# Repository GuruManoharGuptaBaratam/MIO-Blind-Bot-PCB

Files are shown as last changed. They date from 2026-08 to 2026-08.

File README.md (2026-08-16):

<div align="center">

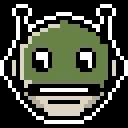
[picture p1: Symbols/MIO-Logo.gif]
MIO Logo


# MIO-Blind-Bot-PCB

**Custom hardware design for MIO — a wearable assistive device for blind and low-vision users**


[]()
[]()
[]()

</div>

---

## About This Repository

This repository contains the complete PCB hardware design for **MIO**, a dual-ESP32 wearable assistive device. The board serves as the central interconnect and power-management platform of the system, tying together the compute modules, motion sensing, camera pan-tilt actuation, display feedback, and battery power delivery into a single wearable-ready design.

This is a hardware-only repository — schematics, PCB layout, manufacturing outputs, and supporting documentation live here. Firmware for the system is maintained separately.

### Key Subsystems

- **Dual ESP32 compute architecture** — separate Core and Inference module footprints
- **ESP32-CAM interconnect** — pan-tilt servo header + camera signal breakout
- **Power management** — single-cell Li-ion BMS input, with onboard 5V (CA-1235) and 3.3V (LM2596) regulation stages
- **IMU integration** — MPU6050 motion/orientation sensor interface
- **Display interface** — 1.8" ST7735 TFT (SPI) connector
- **Servo control headers** — MG90S-compatible pan/tilt outputs

---

## Board Renders

<div align="center">

| Front | Back |
|:---:|:---:|
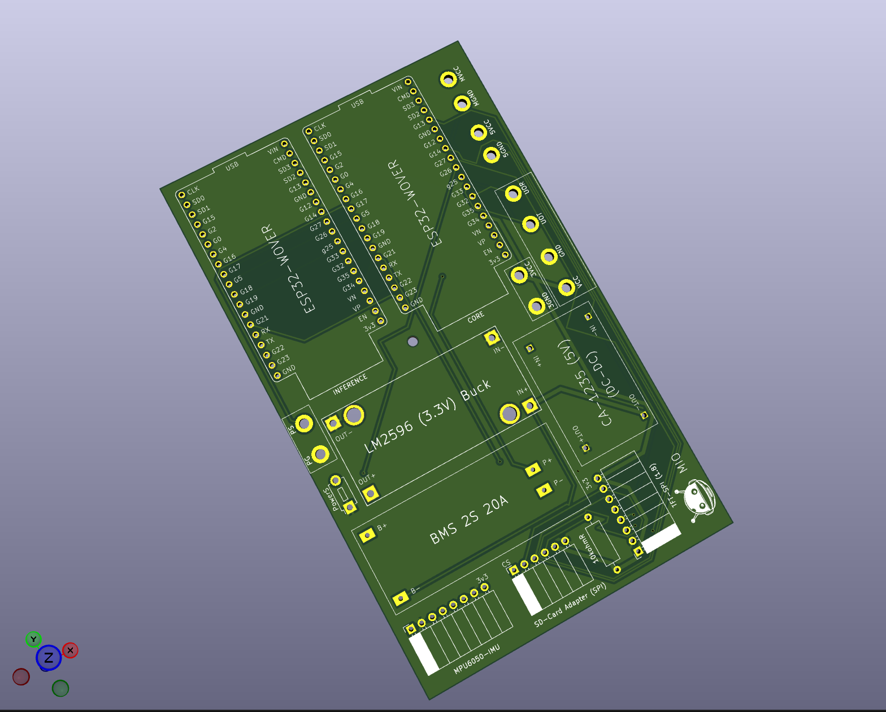
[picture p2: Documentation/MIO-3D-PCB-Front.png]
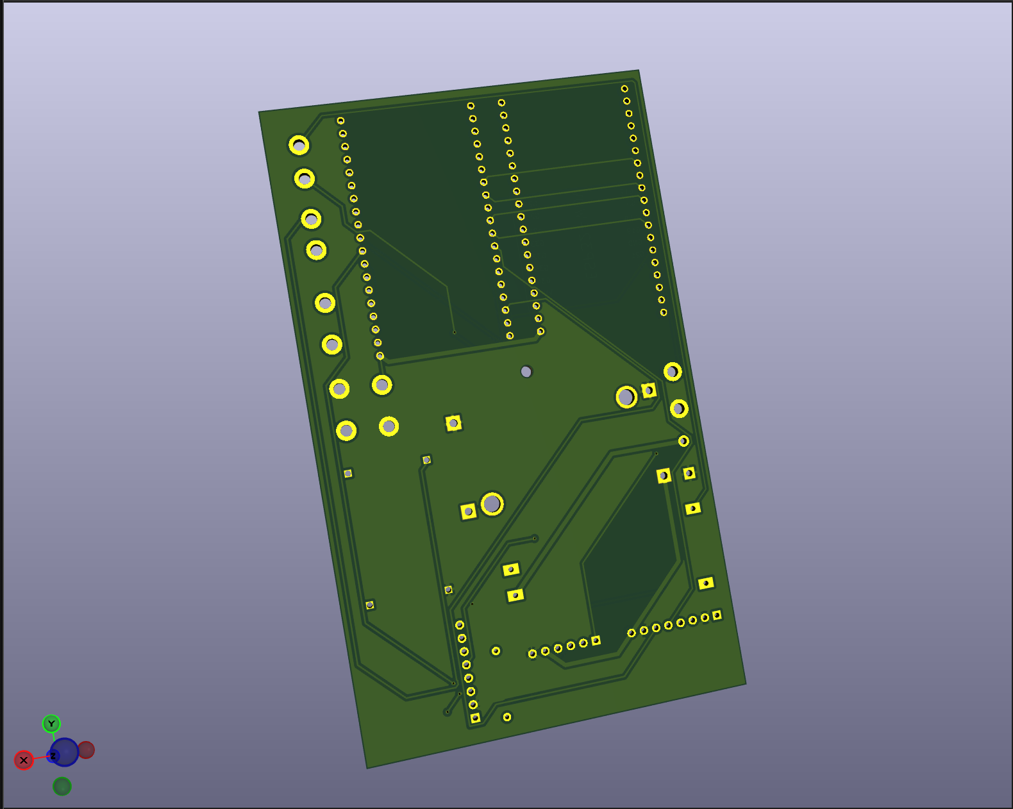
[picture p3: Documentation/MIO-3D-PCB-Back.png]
|  |  |

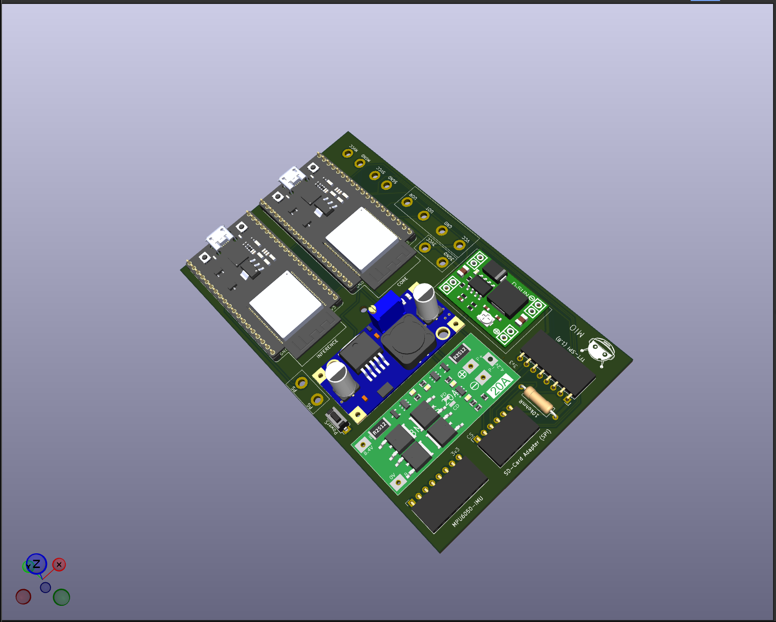
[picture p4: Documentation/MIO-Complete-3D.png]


**[▶ Watch the 3D board walkthrough](Documentation/MIO-3D-Video.mp4)**

</div>

---

## PCB Layout

<div align="center">
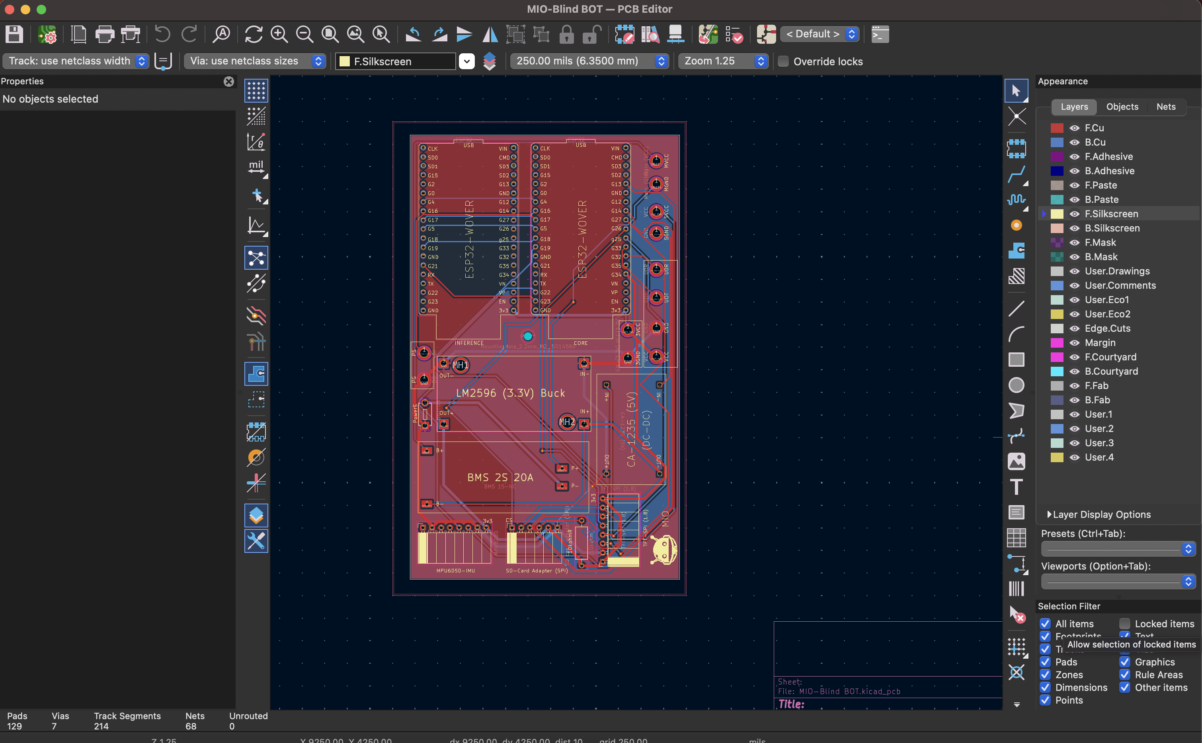
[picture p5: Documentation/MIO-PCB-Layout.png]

</div>

---

## Schematics

The full schematic set is available as PDF for quick review without opening KiCad:

- [MIO Schematic — Sheet 1](Documentation/MIO-Schematic%281%29.pdf)
- [MIO Schematic — Sheet 2](Documentation/MIO-Schematic%282%29.pdf)

For the editable source, see [`Hardware/MIO-Blind BOT.kicad_sch`](Hardware/MIO-Blind%20BOT.kicad_sch).

---

## Footprints & 3D Models

Custom footprints and 3D models used in this design are included so the project can be opened and rendered without missing library references. Each subfolder is a standalone KiCad footprint library (`.pretty`-style) containing the `.kicad_mod` definition and matching `.step` model.

| Folder | Used For |
|---|---|
| [`BMS-2S 20A`](Footprints/BMS-2S%2020A) | Battery management module (U8) |
| [`CA-1235 (Step-Down)`](Footprints/CA-1235%20%28Step-Down%29) | 5V step-down converter (U5) |
| [`ESP32-CAM`](Footprints/ESP32-CAM) | ESP32-CAM module footprint |
| [`ESP32-DEVKITC-32E`](Footprints/ESP32-DEVKITC-32E) | ESP32 DevKit footprint (Core / Inference modules) |
| [`LM2596-Buck(DC-DC)`](Footprints/LM2596-Buck%28DC-DC%29) | 3.3V buck converter (U12) |
| [`MIO-PCB-Logo`](Footprints/MIO-PCB-Logo) | Silkscreen logo footprint |
| [`ON-OFF Switch`](Footprints/ON-OFF%20Switch) | Power on/off switch |

**To use these in KiCad:**

1. Open **Preferences → Manage Footprint Libraries**.
2. Add each folder under [`Footprints/`](Footprints) as its own library entry (or point to the parent folder if your KiCad version supports nested library discovery).
3. Confirm each footprint's **3D Models** tab (Footprint Properties) is correctly linked to its `.step` file — this is what drives the renders in the [Board Renders](#board-renders) section above.

---

## Manufacturing Files

Ready-to-fabricate outputs are provided for direct submission to a PCB manufacturer (JLCPCB, PCBWay, or equivalent), plus a Bill of Materials for sourcing components.

<div align="center">

### [⬇ Download Gerbers (MIO-Gerber.zip)](Manfacturing/MIO-Gerber.zip) &nbsp;|&nbsp; [⬇ Download BOM (MIO-Blind BOT.csv)](Manfacturing/MIO-Blind%20BOT.csv)

</div>

| File / Folder | Description |
|---|---|
| [`MIO-Gerber.zip`](Manfacturing/MIO-Gerber.zip) | Complete Gerber file set for fabrication |
| [`MIO-Gerbers/`](Manfacturing/MIO-Gerbers) | Unpacked Gerber layer files |
| [`MIO-Drill/`](Manfacturing/MIO-Drill) | Drill files (NC drill / Excellon) |
| [`MIO-Blind BOT.csv`](Manfacturing/MIO-Blind%20BOT.csv) | Bill of Materials (BOM) |

---

## Repository Structure

```
MIO-Blind-Bot-PCB/
├── Documentation/
│   ├── MIO-3D-PCB-Back.png
│   ├── MIO-3D-PCB-Front.png
│   ├── MIO-3D-Video.mp4
│   ├── MIO-Complete-3D.png
│   ├── MIO-PCB-Layout.png
│   ├── MIO-Schematic(1).pdf
│   └── MIO-Schematic(2).pdf
├── Hardware/
│   ├── MIO-Blind BOT.kicad_pcb
│   ├── MIO-Blind BOT.kicad_pro
│   └── MIO-Blind BOT.kicad_sch
├── Manfacturing/
│   ├── MIO-Drill/
│   ├── MIO-Gerbers/
│   ├── MIO-Blind BOT.csv
│   └── MIO-Gerber.zip
├── Footprints/
│   ├── BMS-2S 20A/
│   ├── CA-1235 (Step-Down)/
│   ├── ESP32-CAM/
│   ├── ESP32-DEVKITC-32E/
│   ├── LM2596-Buck(DC-DC)/
│   ├── MIO-PCB-Logo/
│   └── ON-OFF Switch/
├── Symbols/
│   └── MIO-Logo.gif
└── README.md
```

---

## Design Environment

| | |
|---|---|
| **EDA Tool** | [KiCad](https://www.kicad.org/) 10.0 |
| **Layers** | 2-layer (F.Cu / B.Cu) |
| **Design Type** | Wearable power & interconnect board |
| **First Revision** | First custom PCB design for the MIO project |

---

## Getting Started

To open and edit this design locally:

1. Install [KiCad](https://www.kicad.org/download/) (v8 or later recommended).
2. Clone this repository:
   ```bash
        git clone https://github.com/GuruManoharGuptaBaratam/MIO-Blind-Bot-PCB.git
   ```
3. Open [`Hardware/MIO-Blind BOT.kicad_pro`](Hardware/MIO-Blind%20BOT.kicad_pro) in KiCad.

To order the board as-is, download [`MIO-Gerber.zip`](Manfacturing/MIO-Gerber.zip) above and upload it directly to your preferred PCB fabricator. Use [`MIO-Blind BOT.csv`](Manfacturing/MIO-Blind%20BOT.csv) to source and place components.

---

## Roadmap

- [x] Footprint library (`.kicad_mod`) and 3D models (`.step`)
- [ ] Bring-up and test notes

---

## License

License to be finalized — see repository for updates.

---

<div align="center">
<sub>Part of the <b>MIO</b> project.</sub>
</div>

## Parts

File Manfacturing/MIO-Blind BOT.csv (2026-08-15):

Reference | Qty | Value | DNP | Exclude from BOM | Exclude from Board | Exclude from Simulation | Exclude from Position Files | Footprint | Datasheet
U12 | 1 | LM2596 (3.3v) |  |  |  |  | ${EXCLUDE_FROM_POS_FILES} | LM2596-Buck(DC-DC):CONV_USA_MC00100
U11 | 1 | BUTTON |  |  |  |  | ${EXCLUDE_FROM_POS_FILES} | Button_Switch_THT:SW_PUSH_1P1T_6x3.5mm_H5.0_APEM_MJTP1250
U9 | 1 | TFT SPI (1.8) |  |  |  |  | ${EXCLUDE_FROM_POS_FILES} | Connector_PinSocket_2.54mm:PinSocket_1x08_P2.54mm_Horizontal
U8 | 1 | BMS 1S-NC |  |  |  |  | ${EXCLUDE_FROM_POS_FILES} | BMS-2S 20A:BMS-2S 20A
U5 | 1 | CA-1235 (5V) |  |  |  |  | ${EXCLUDE_FROM_POS_FILES} | CA-1235 (Step-Down):Converter_MP1495_Module
U4 | 1 | SD card adapter (SPI) |  |  |  |  | ${EXCLUDE_FROM_POS_FILES} | Connector_PinSocket_2.54mm:PinSocket_1x06_P2.54mm_Horizontal
P1 | 1 | MPU6050 |  |  |  |  | ${EXCLUDE_FROM_POS_FILES} | Connector_PinSocket_2.54mm:PinSocket_1x08_P2.54mm_Horizontal
L1 | 1 | (10kohm) |  |  |  |  | ${EXCLUDE_FROM_POS_FILES} | Resistor_THT:R_Axial_DIN0309_L9.0mm_D3.2mm_P12.70mm_Horizontal
CORE1,INFERENCE1 | 2 | ESP32 |  |  |  |  | ${EXCLUDE_FROM_POS_FILES} | ESP32-DEVKITC-32E:MODULE_ESP32-DEVKITC-32E

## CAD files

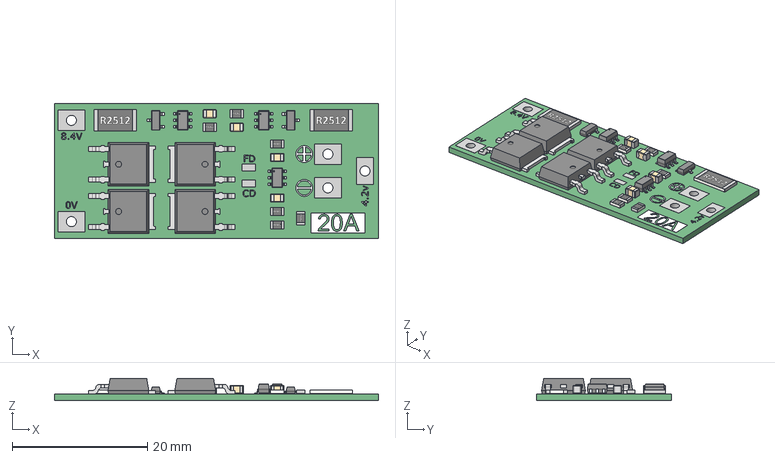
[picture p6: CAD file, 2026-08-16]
Footprints/BMS-2S 20A/HW-391 2S 20A BMS.step
48.0 x 20.0 x 3.31 mm

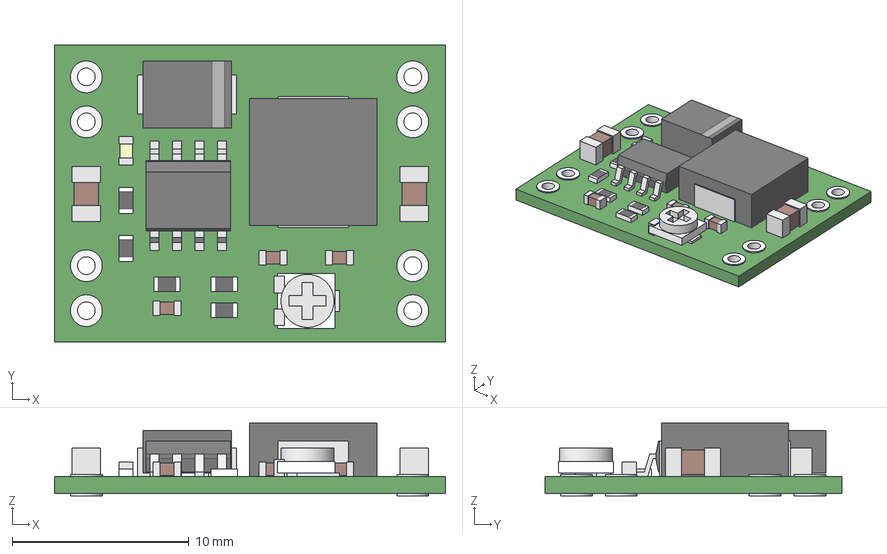
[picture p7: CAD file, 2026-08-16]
Footprints/CA-1235 (Step-Down)/D-SUN_dcdc_step_down_Simple_NoSilk_.step
22.1 x 16.8 x 4.10 mm
main001
pins
comp-top

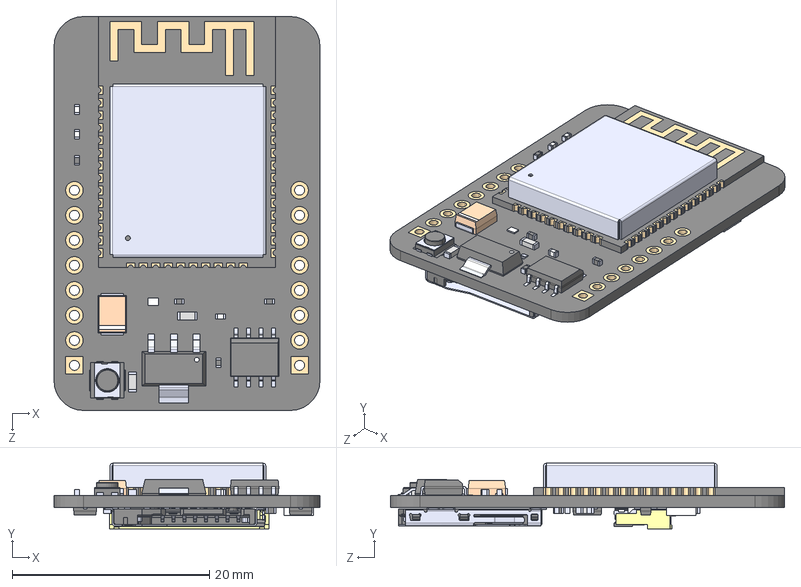
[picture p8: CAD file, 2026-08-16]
Footprints/ESP32-CAM/ESP32-CAM.step
27.0 x 6.65 x 40.0 mm

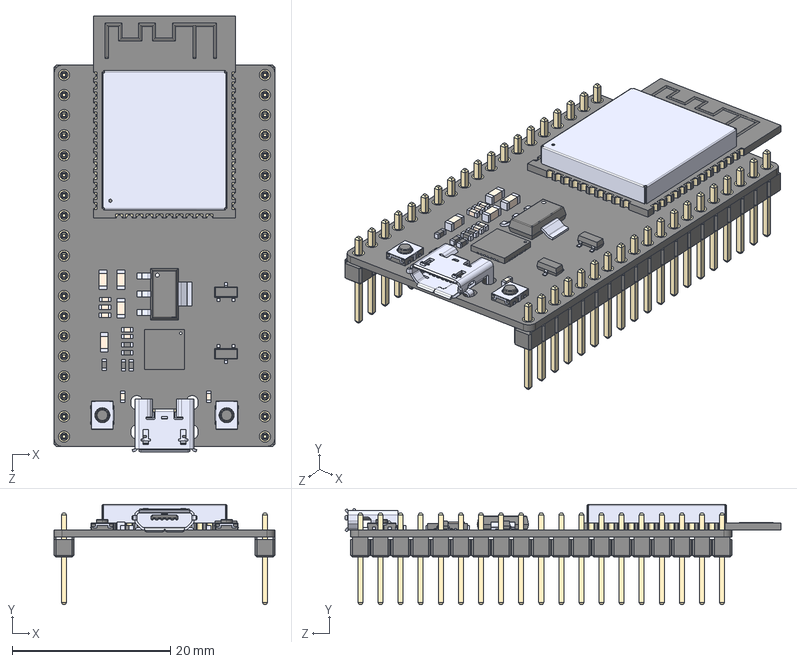
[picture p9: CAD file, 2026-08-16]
Footprints/ESP32-DEVKITC-32E/ESP32-DEVKITC-32E.step
27.9 x 12.7 x 55.1 mm
board
header x 2
ESP32-WROOM-32D
micro usb
button x 2
CP2102N-A01-GQFN28
AMS1117-3.3
SS8050-G
components^DEVKIT V1 ESP32-WROOM-32

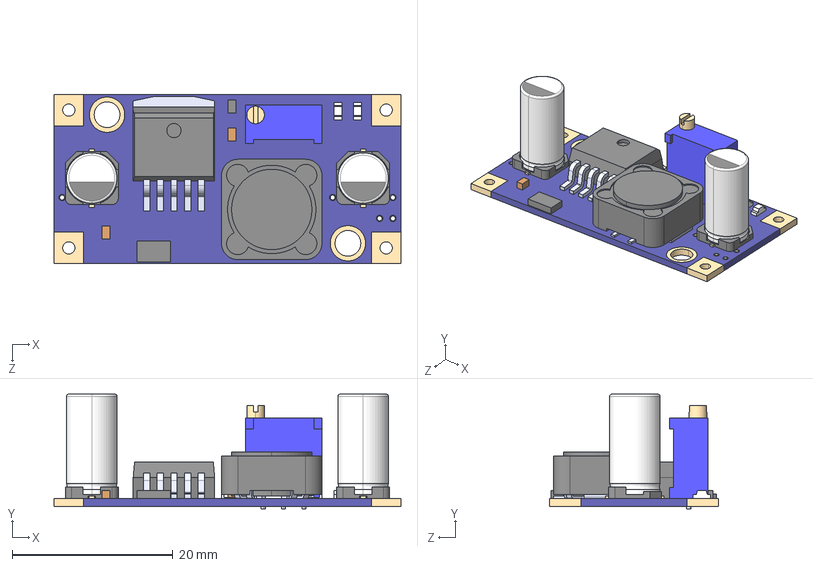
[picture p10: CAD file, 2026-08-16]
Footprints/LM2596-Buck(DC-DC)/007-386628000331258--3DModel-STEP-269445.STEP
43.2 x 14.3 x 21.1 mm
MC00100
3296W-1-104
DR125-331-R
LM2596DSADJG
EEE1HA470XAP x 2

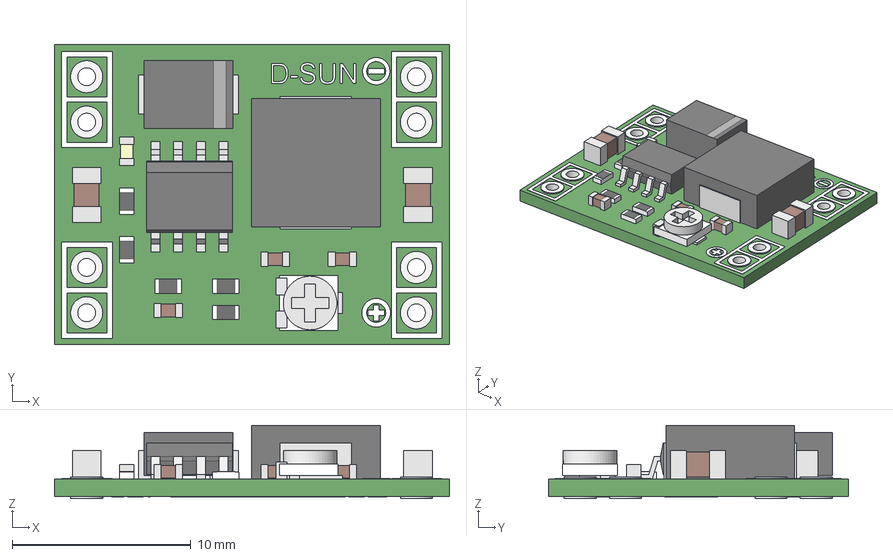
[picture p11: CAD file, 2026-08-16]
Footprints/CA-1235 (Step-Down)/D-SUN_dcdc_step_down_SIMPLE.step
22.1 x 16.8 x 4.10 mm
main001
silk-TOP
pins
silk-bot
comp-top

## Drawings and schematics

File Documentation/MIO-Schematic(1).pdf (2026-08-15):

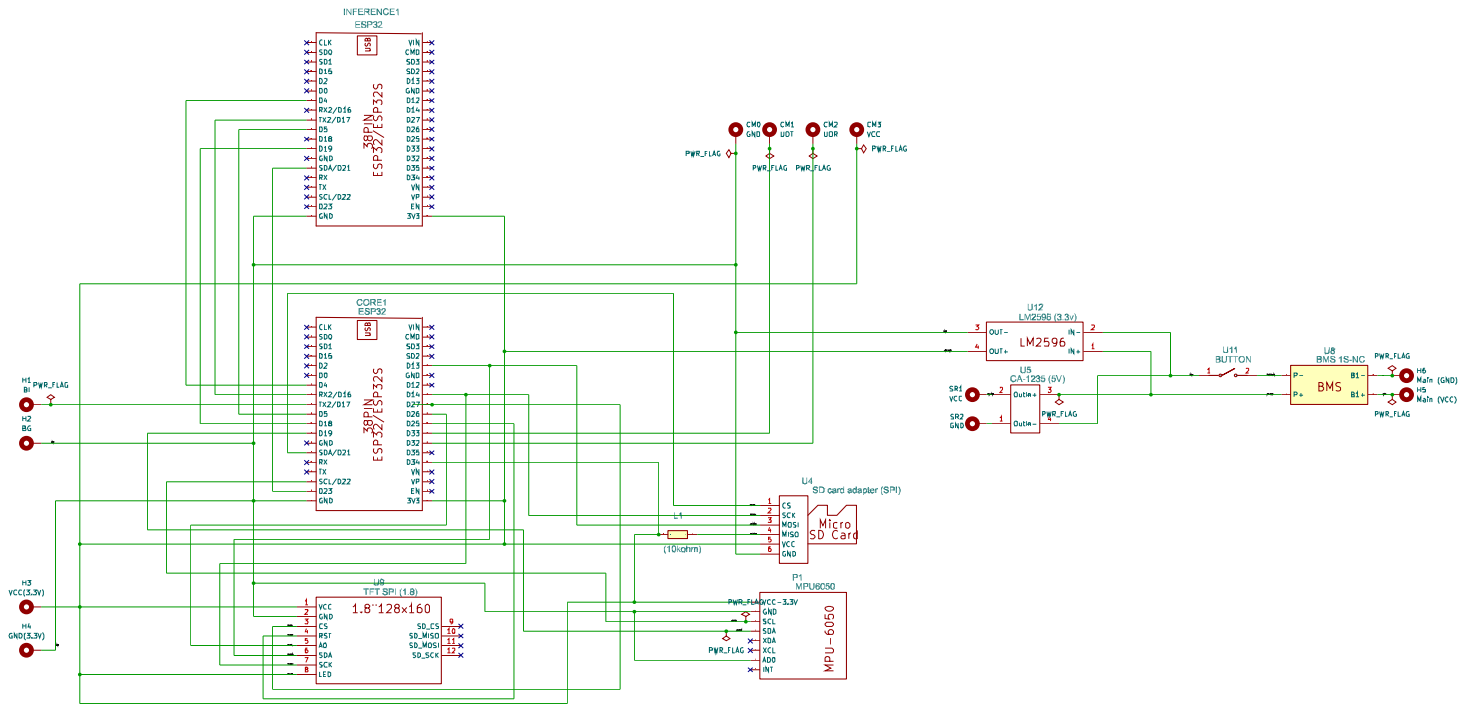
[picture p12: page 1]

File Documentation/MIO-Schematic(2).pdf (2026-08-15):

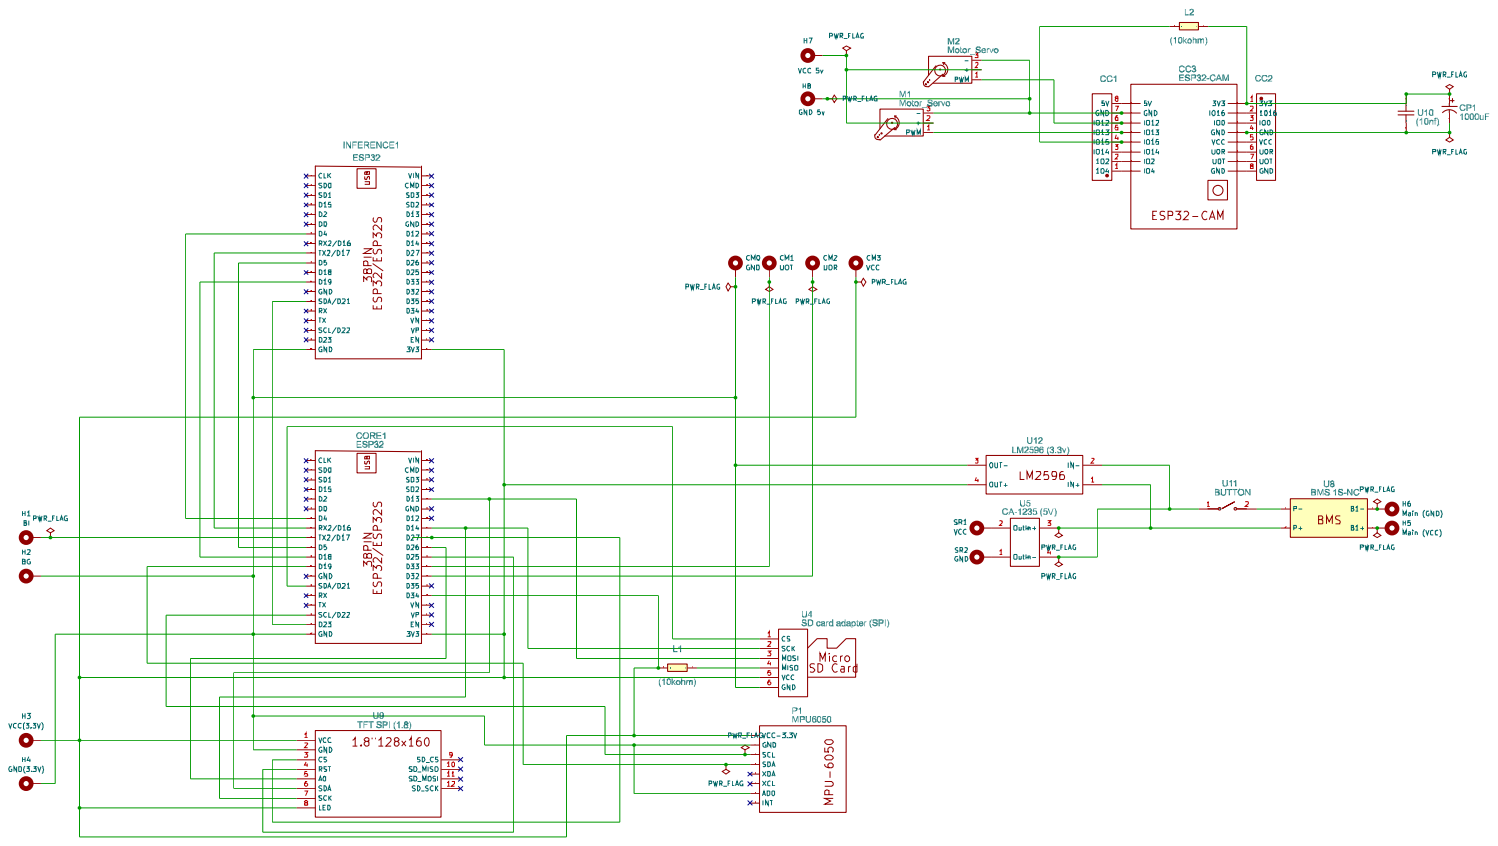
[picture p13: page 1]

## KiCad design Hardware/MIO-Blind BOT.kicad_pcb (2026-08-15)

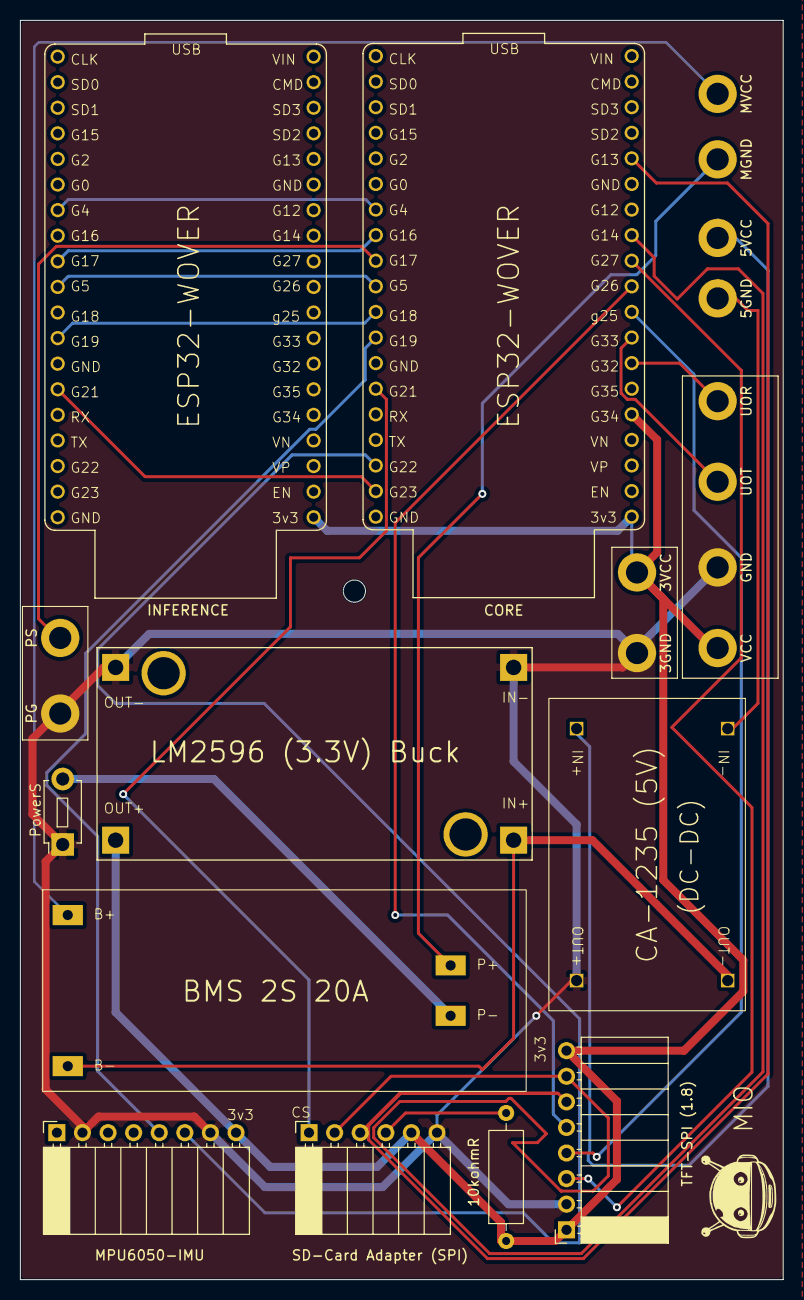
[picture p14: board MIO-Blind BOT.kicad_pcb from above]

Board: 2 copper layers, 75.7 x 125.0 mm, 22 parts (0 on the bottom side), 25 nets.

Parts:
3GND: GND(3.3V); MountingHole_2.2mm_M2_DIN965_Pad
3VCC: VCC(3.3V); MountingHole_2.2mm_M2_DIN965_Pad
5GND: GND; MountingHole_2.2mm_M2_DIN965_Pad
5VCC: VCC; MountingHole_2.2mm_M2_DIN965_Pad
10kohmR: (10kohm); R_Axial_DIN0309_L9.0mm_D3.2mm_P12.70mm_Horizontal
BMS 2S 20A: BMS 1S-NC; BMS-2S 20A
CA-1235 (5V): CA-1235 (5V); Converter_MP1495_Module
CORE: ESP32; MODULE_ESP32-DEVKITC-32E
GND: GND; MountingHole_2.2mm_M2_DIN965_Pad
INFERENCE: ESP32; MODULE_ESP32-DEVKITC-32E
MGND: Main (GND); MountingHole_2.2mm_M2_DIN965_Pad
MPU6050-IMU: MPU6050; PinSocket_1x08_P2.54mm_Horizontal
MVCC: Main (VCC); MountingHole_2.2mm_M2_DIN965_Pad
PG: BG; MountingHole_2.2mm_M2_DIN965_Pad
PS: BI; MountingHole_2.2mm_M2_DIN965_Pad
PowerS: BUTTON; SW_PUSH_1P1T_6x3.5mm_H5.0_APEM_MJTP1250
SD-Card Adapter (SPI): SD card adapter (SPI); PinSocket_1x06_P2.54mm_Horizontal
TFT-SPI (1.8): TFT SPI (1.8); PinSocket_1x08_P2.54mm_Horizontal
U12: LM2596 (3.3v); CONV_USA_MC00100
UOR: UOR; MountingHole_2.2mm_M2_DIN965_Pad
UOT: UOT; MountingHole_2.2mm_M2_DIN965_Pad
VCC: VCC; MountingHole_2.2mm_M2_DIN965_Pad

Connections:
/+3V3_PWR: 3VCC.1 (1_1), 10kohmR.1, CORE.3V3, CORE.D34, INFERENCE.3V3, MPU6050-IMU.8 (VCC-3.3V), SD-Card Adapter (SPI).5 (VCC), TFT-SPI (1.8).1 (VCC), TFT-SPI (1.8).8 (LED), U12.4 (OUT+), VCC.1 (1_1)
/+5V_PWR: 5VCC.1 (1_1), CA-1235 (5V).2 (Out+)
/GND: 3GND.1 (1_1), CA-1235 (5V).4 (In-), GND.1 (1_1), MPU6050-IMU.2 (AD0), MPU6050-IMU.7 (GND), PG.1 (1_1), PowerS.1, SD-Card Adapter (SPI).6 (GND), TFT-SPI (1.8).2 (GND), U12.2 (IN-), U12.3 (OUT-)
/I2C_SCL: CORE.D22 (SCL/D22), MPU6050-IMU.6 (SCL)
/I2S_SDA: CORE.D19, MPU6050-IMU.5 (SDA)
/PWR_SW_IN: BMS 2S 20A.3 (P-), PowerS.2
/SD_CS: CORE.D21 (SDA/D21), SD-Card Adapter (SPI).1 (CS)
/SD_MISO: 10kohmR.2, SD-Card Adapter (SPI).4 (MISO)
/SD_MOSI: CORE.D13, SD-Card Adapter (SPI).3 (MOSI), TFT-SPI (1.8).6 (SDA)
/SD_SCK: CORE.D14, SD-Card Adapter (SPI).2 (SCK), TFT-SPI (1.8).7 (SCK)
/TFT_CS: CORE.D27, TFT-SPI (1.8).3 (CS)
/TFT_DC: CORE.D26, TFT-SPI (1.8).5 (A0)
/TFT_RST: CORE.D25, TFT-SPI (1.8).4 (RST)
/VBAT+: BMS 2S 20A.4 (B1-), MGND.1 (1_1)
/VBAT-: BMS 2S 20A.1 (B1+), MVCC.1 (1_1)
/VCC_SYS: BMS 2S 20A.2 (P+), CA-1235 (5V).3 (In+), U12.1 (IN+)
unnamed: CORE.D33, UOT.1 (1_1)
unnamed: CORE.D32, UOR.1 (1_1)
unnamed: CORE.D4, INFERENCE.D4
unnamed: CORE.D5, INFERENCE.D5
unnamed: CORE.D18, INFERENCE.D19
unnamed: CORE.D16 (RX2/D16), INFERENCE.D17 (TX2/D17)
unnamed: CORE.D17 (TX2/D17), PS.1 (1_1)
unnamed: CORE.D23, INFERENCE.D21 (SDA/D21)
unnamed: 5GND.1 (1_1), CA-1235 (5V).1 (Out-)

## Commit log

2026-08-15 MIO-PCB: Adding Files
    [MIO-Blind BOT-B_Cu.gbr, MIO-Blind BOT-B_Mask.gbr, MIO-Blind BOT-B_Paste.gbr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]
2026-08-15 MIO-PCB: Readme.md update
2026-08-16 MIO-PCB: Footprints Added
    [007-386628000331258--3DModel-STEP-269445.STEP, D-SUN_dcdc_step_down_SIMPLE.step, D-SUN_dcdc_step_down_Simple_NoSilk_.step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]
2026-08-16 MIO-PCB: Readme.md updated

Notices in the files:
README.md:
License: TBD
